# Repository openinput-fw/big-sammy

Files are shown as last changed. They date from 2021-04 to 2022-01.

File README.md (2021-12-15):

# big-sammy



[](https://github.com/openinput-fw)

Open source wired mouse hardware.

Please see the [documentation](https://big-sammy.readthedocs.io/en/latest) for more information.

## Specifications
- 8 kHz sampling rate support
- Zero latency switch debounce
- Onboard configuration memory
- 2 main mouse buttons (satellite* configuration for both)
- 2 side buttons (symmetric to allow easy left/right handedness)
- encoder + wheel button (satellite* configuration)
- RGB Led

`*meaning, a separate board from the core with the controller and sensor`

## Firmware

*big-sammy* is meant to run on [openinput](https://github.com/openinput-fw/openinput).

## License

This hardware is licensed under the [CERN-OHL-P v2](LICENSE) license.

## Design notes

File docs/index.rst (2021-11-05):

:hide-toc:

*********
big-sammy
*********
*big-sammy* is an open source wired mouse hardware implementation.

State of the project
====================

First prototype under testing, firmware support for openinput_ under development.

.. admonition:: Roadmap

   - Initial design |:+1:|
   - First prototype manufactured and assembled |:+1:|
   - Barebones firmware support |:+1:|
   - Documentation |:hammer:|
   - Hardware improvements |:hammer:|
   - First release

   ========== ================
   |:+1:|     Done!
   |:hammer:| Work in progress
   ========== ================

Specifications
==============

* 8 kHz sampling rate support
* Zero latency switch debounce
* Onboard configuration memory
* 2 main mouse buttons (satellite* configuration for both)
* 2 side buttons (symmetric to allow easy left/right handedness)
* encoder + wheel button (satellite* configuration)
* RGB Led

Hardware
========

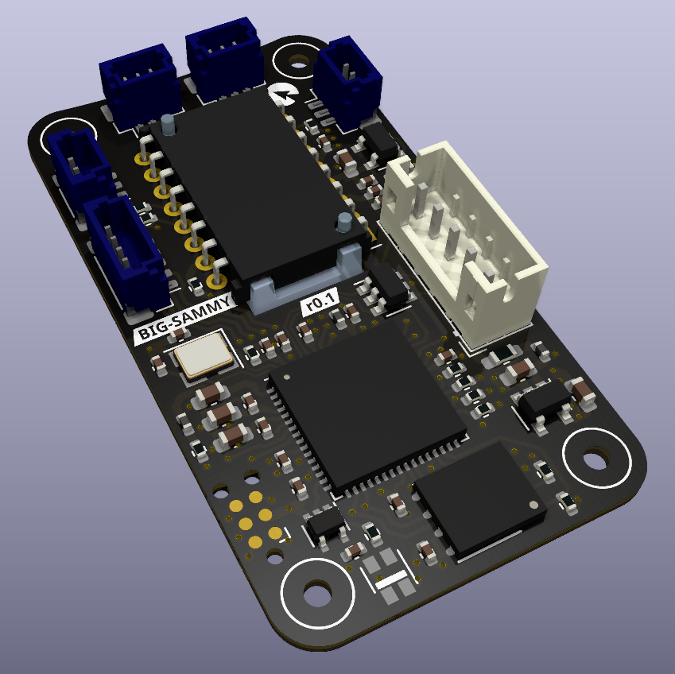
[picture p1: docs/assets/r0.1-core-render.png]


* ATSAMS70 MCU (ATSAMS70JxxB-M)
* Optical sensor [PMW3330, PMW3360, PMW3389, Truemove3]
* onboard conectors:
   * JST PH (2mm pitch) for USB
   * JST SH (1mm pitch) for stellite boards
* M2 mounting hardware

+--------------+
| USB   pinout |
+-----+--------+
| pin | func   |
+=====+========+
| 1 	| VCC    |
+-----+--------+
| 2 	| DM     |
+-----+--------+
| 3 	| DP     |
+-----+--------+
| 4 	| GND    |
+-----+--------+
| 5 	| Shield |
+-----+--------+

Peripheral boards are used for the buttons and encoder, available at generic-mouse-boards.

.. toctree::
   :caption: Development
   :hidden:

   Contributing <contributing/index>

.. toctree::
   :caption: External Links
   :hidden:

   Source <https://github.com/openinput-fw/big-sammy>
   Firmware <https://openinput.readthedocs.io>
   Issue Tracker <https://github.com/openinput-fw/big-sammy/issues>

.. _openinput: https://openinput.readthedocs.io

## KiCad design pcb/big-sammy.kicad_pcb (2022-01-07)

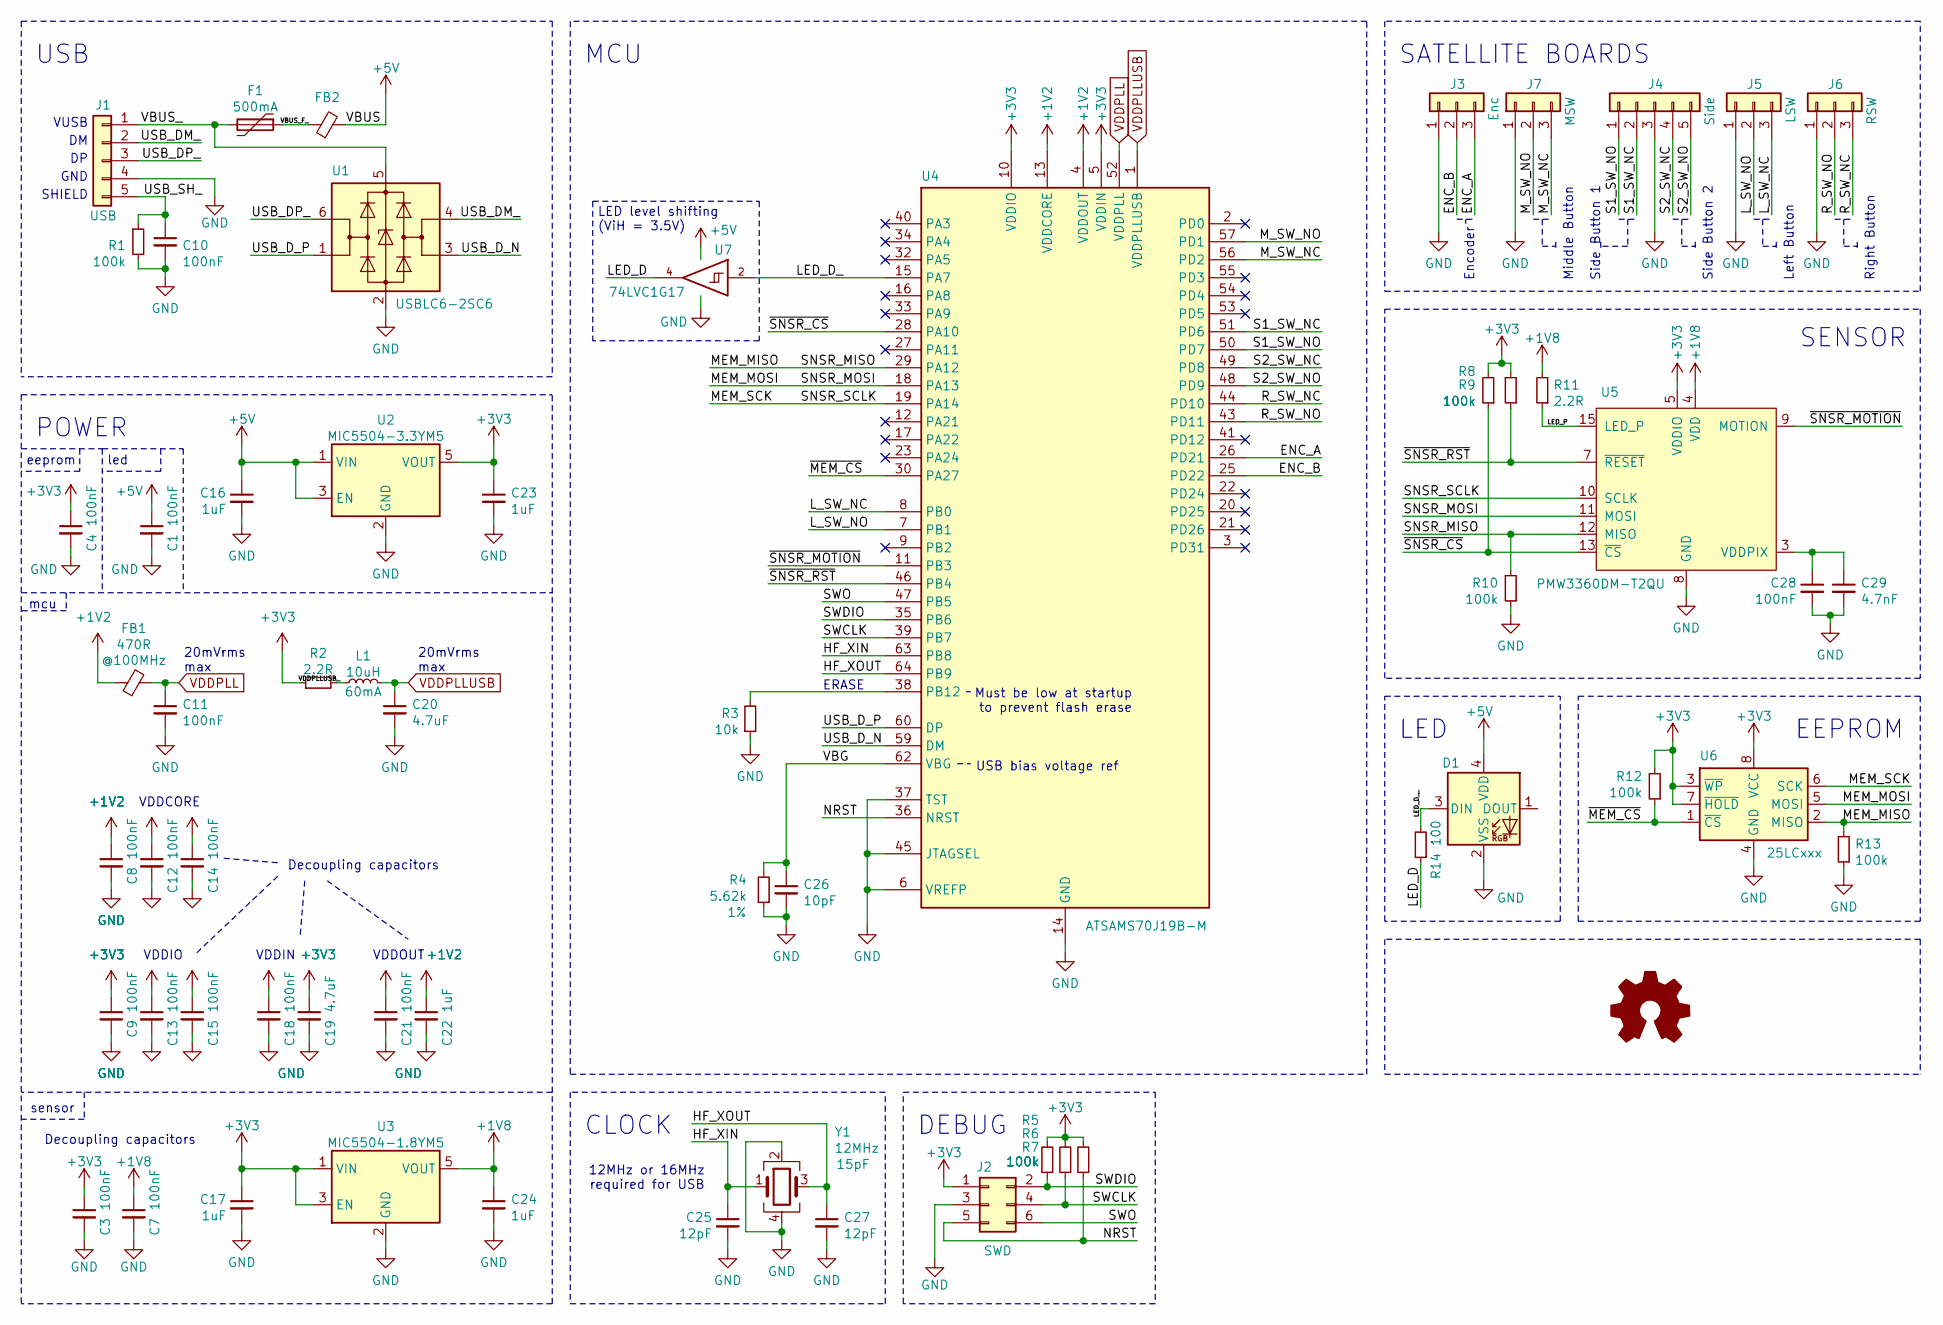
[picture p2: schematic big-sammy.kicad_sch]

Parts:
C1, C3, C4, C7, C8, C9, C10, C11, C12, C13, C14, C15, C18, C21, C28: 100nF; C_0402_1005Metric
C16, C17, C22, C23, C24: 1uF; C_0603_1608Metric
C19, C20: 4.7uF; C_0603_1608Metric
C25, C27: 12pF; C_0402_1005Metric
C26: 10pF; C_0402_1005Metric
C29: 4.7nF; C_0402_1005Metric
D1: ws2812-2020
F1: 500mA; Fuse_0603_1608Metric_Castellated
FB1: 470R; L_0402_1005Metric
FB2: L_0402_1005Metric
J1: USB; JST_PH_B5B-PH-K_1x05_P2.00mm_Vertical
J2: SWD; Tag-Connect_TC2030-IDC-NL_2x03_P1.27mm_Vertical
J3: Enc; JST_SH_BM03B-SRSS-TB_1x03-1MP_P1.00mm_Vertical
J4: Side; JST_SH_BM05B-SRSS-TB_1x05-1MP_P1.00mm_Vertical
J5: LSW; JST_SH_BM03B-SRSS-TB_1x03-1MP_P1.00mm_Vertical
J6: RSW; JST_SH_BM03B-SRSS-TB_1x03-1MP_P1.00mm_Vertical
J7: MSW; JST_SH_BM03B-SRSS-TB_1x03-1MP_P1.00mm_Vertical
L1: 10uH; L_0402_1005Metric
R1, R5, R6, R7, R8, R9, R10, R12, R13: 100k; R_0402_1005Metric
R2, R11: 2.2R; R_0402_1005Metric
R3: 10k; R_0402_1005Metric
R4: 5.62k; R_0402_1005Metric; Tolerance 1%
R14: 100; R_0402_1005Metric
U1: USBLC6-2SC6; SOT-23-6
U2: MIC5504-3.3YM5; SOT-23-5
U3: MIC5504-1.8YM5; SOT-23-5
U4: ATSAMS70J19B-M; QFN-64-1EP_9x9mm_P0.5mm_EP7.65x7.65mm
U5: PMW3360DM-T2QU; PMW3360
U6: 25LCxxx; DFN-S-8-1EP_6x5mm_P1.27mm
U7: 74LVC1G17; SOT-353_SC-70-5
Y1: 12MHz; Crystal_SMD_3225-4Pin_3.2x2.5mm

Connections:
+1V2: C8.1, C12.1, C14.1, C21.1, C22.1, FB1.1, U4.4 (VDDOUT), U4.13 (VDDCORE), U4.24 (VDDCORE), U4.61 (VDDCORE)
+1V8: C7.1, C24.1, R11.2, U3.5 (VOUT), U5.4 (VDD)
+3V3: C3.1, C4.1, C9.1, C13.1, C15.1, C17.1, C18.1, C19.1, C23.1, J2.1, R2.1, R5.2, R6.2, R7.2, R8.2, R9.2, R12.2, U2.5 (VOUT), U3.1 (VIN), U3.3 (EN), U4.5 (VDDIN), U4.10 (VDDIO), U4.42 (VDDIO), U4.58 (VDDIO), U5.5 (VDDIO), U6.3 (~WP), U6.7 (~HOLD), U6.8 (VCC)
+5V: C1.1, C16.1, D1.4 (VDD), FB2.2, U2.1 (VIN), U2.3 (EN), U7.5 (VCC)
/ENC_A: J3.3, U4.26 (PD21)
/ENC_B: J3.2, U4.25 (PD22)
/HF_XIN: C25.1, U4.63 (PB8), Y1.1
/HF_XOUT: C27.1, U4.64 (PB9), Y1.3
/LED_D: R14.1, U7.4
/LED_D_: U4.15 (PA7), U7.2
/LED_D__: D1.3 (DIN), R14.2
/LED_P: R11.1, U5.15 (LED_P)
/L_SW_NC: J5.3, U4.8 (PB0)
/L_SW_NO: J5.2, U4.7 (PB1)
/MEM_MISO: R10.2, R13.2, U4.29 (PA12), U5.12 (MISO), U6.2 (MISO)
/MEM_MOSI: U4.18 (PA13), U5.11 (MOSI), U6.5 (MOSI)
/MEM_SCK: U4.19 (PA14), U5.10 (SCLK), U6.6 (SCK)
/M_SW_NC: J7.3, U4.56 (PD2)
/M_SW_NO: J7.2, U4.57 (PD1)
/NRST: J2.5, R7.1, U4.36 (NRST)
/R_SW_NC: J6.3, U4.44 (PD10)
/R_SW_NO: J6.2, U4.43 (PD11)
/S1_SW_NC: J4.2, U4.51 (PD6)
/S1_SW_NO: J4.1, U4.50 (PD7)
/S2_SW_NC: J4.4, U4.49 (PD8)
/S2_SW_NO: J4.5, U4.48 (PD9)
/SWCLK: J2.4, R6.1, U4.39 (PB7)
/SWDIO: J2.2, R5.1, U4.35 (PB6)
/SWO: J2.6, U4.47 (PB5)
/USB_DM_: J1.2, U1.4 (I/O2)
/USB_DP_: J1.3, U1.6 (I/O1)
/USB_D_N: U1.3 (I/O2), U4.59 (DM)
/USB_D_P: U1.1 (I/O1), U4.60 (DP)
/USB_SH_: C10.1, J1.5, R1.1
/VBG: C26.1, R4.2, U4.62 (VBG)
/VBUS_: F1.2, J1.1, U1.5 (VBUS)
/VBUS_F_: F1.1, FB2.1
/VDDPLLUSB_: L1.1, R2.2
/~MEM_CS: R12.1, U4.30 (PA27), U6.1 (~CS)
/~SNSR_CS: R8.1, U4.28 (PA10), U5.13 (~CS)
/~SNSR_MOTION: U4.11 (PB3), U5.9 (MOTION)
/~SNSR_RST: R9.1, U4.46 (PB4), U5.7 (~RESET)
GND: C1.2, C3.2, C4.2, C7.2, C8.2, C9.2, C10.2, C11.2, C12.2, C13.2, C14.2, C15.2, C16.2, C17.2, C18.2, C19.2, C20.2, C21.2, C22.2, C23.2, C24.2, C25.2, C26.2, C27.2, C28.2, C29.2, D1.2 (VSS), J1.4, J2.3, J3.1, J4.3, J5.1, J6.1, J7.1, R1.2, R3.1, R4.1, R10.1, R13.1, U1.2 (GND), U2.2 (GND), U3.2 (GND), U4.6 (VREFP), U4.14 (GND), U4.31 (GND), U4.37 (TST), U4.45 (JTAGSEL), U4.65 (GND), U5.8 (GND), U6.4 (GND), U7.3 (GND), Y1.2, Y1.4
unnamed: C28.1, C29.1, U5.3 (VDDPIX)
unnamed: R3.2, U4.38 (PB12)
VDDPLL: C11.1, FB1.2, U4.52 (VDDPLL)
VDDPLLUSB: C20.1, L1.2, U4.1 (VDDPLLUSB)

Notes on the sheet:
Side Button 2
Left Button
DEBUG
USB
20mVrms max
CLOCK
SENSOR
USB bias voltage ref
VDDCORE
SHIELD
Right Button
VUSB
led
MCU
12MHz or 16MHz required for USB
mcu
Decoupling capacitors
Side Button 1
GND
POWER
sensor
Encoder
Middle Button
eeprom
SATELLITE BOARDS
VDDIO
LED
ERASE
LED level shifting (ViH = 3.5V)
VDDIN
Must be low at startup to prevent flash erase
EEPROM
VDDOUT

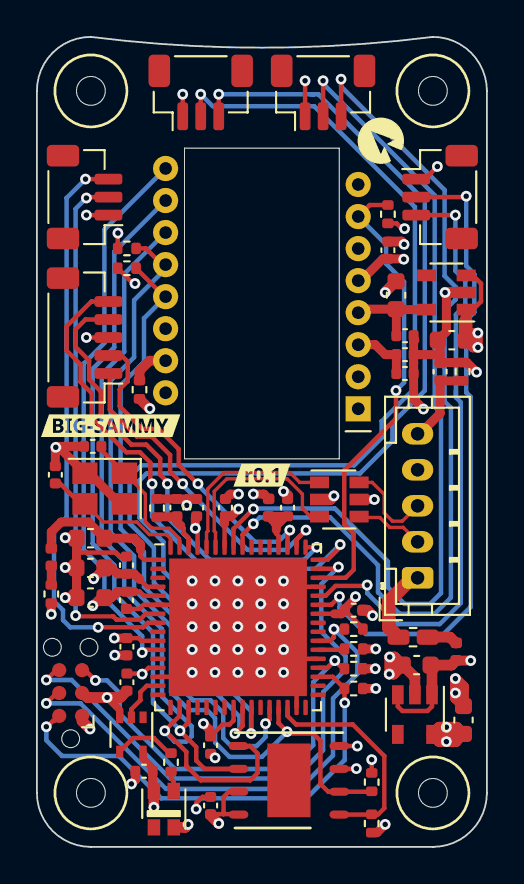
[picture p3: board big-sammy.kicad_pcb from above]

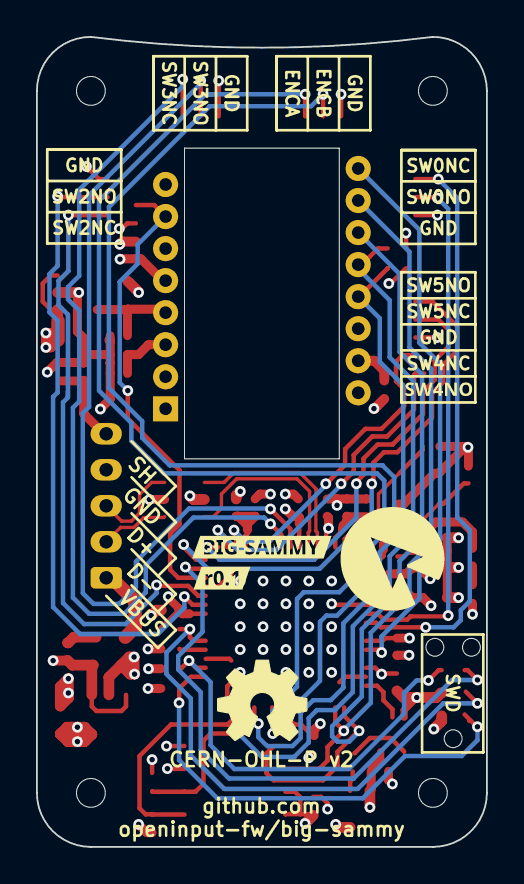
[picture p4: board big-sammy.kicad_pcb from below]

Board: 4 copper layers, 25.0 x 45.0 mm, 65 parts (3 on the bottom side), 47 nets.

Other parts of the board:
svg2mod, svg2mod#2, svg2mod#3, svg2mod#4, svg2mod#5: G***; svg2mod

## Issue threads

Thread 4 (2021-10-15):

Automated PCB and pinout renders for documentation

perigoso, 2021-10-15:
There are a couple projects out there that make pretty renders of pcb related stuff, it's something I'd like to play around with.

This issue serves as a reminder. (help is welcome ofcourse)

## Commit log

2021-04-10 hardware: add base projects
    [core.kicad_pcb, core.kicad_sch, encoder.kicad_pcb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]
2021-04-13 kicad: add local libraries
2021-04-13 schematic: implement core board
    [core.kicad_sch]
2021-04-13 schematic: add current repo url
    [encoder.kicad_sch, side.kicad_sch, switch.kicad_sch]
2021-04-13 git: kicad: add kicad lib backups to gitignore
2021-04-13 schematic: implement side boards
    [encoder.kicad_sch, side.kicad_sch, switch.kicad_sch]
2021-04-13 schematic: add missing library table
2021-04-13 schematic: core: add rgb led
    [core.kicad_sch]
2021-04-13 schematic: core: add labels
    [core.kicad_sch]
2021-04-13 readme: add RGB Led to spec list
2021-04-13 schematic: core: fix erase pull down value (internall 100k in parallel)
    [core.kicad_sch]
2021-04-13 name: renamed project
    [core.kicad_pcb, core.kicad_sch, encoder.kicad_pcb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]
2021-04-13 readme: mention more compatible sensors
2021-04-13 hardware: add project footprint table
2021-04-13 hardware: fix kicad table links
2021-04-13 schematic: core: changed encoder board pinout
    [core.kicad_sch]
2021-04-13 pcb: encoder: layout
    [encoder.kicad_pcb, encoder.kicad_sch]
2021-04-13 pcb: side: layout
    [side.kicad_pcb, side.kicad_sch]
2021-04-13 pcb: switch: layout
    [switch.kicad_pcb, switch.kicad_sch]
2021-04-20 pcb: core: component positioning
    [core.kicad_pcb, core.kicad_sch]
2021-04-21 kicad: libraries
2021-04-21 core: layout
    [core.kicad_pcb, core.kicad_sch]
2021-04-22 kicad: add M1.4 mounting hole
2021-04-22 core: finalize layout
    [core.kicad_pcb]
2021-04-22 switch: add alternative mounting points
    [switch.kicad_pcb]
2021-04-22 side: change mounting hardware from m2 to m1.4
    [side.kicad_pcb]
2021-04-22 encoder: rework encoder board
    [encoder.kicad_pcb, encoder.kicad_sch]
2021-04-22 rev: bum rev to r0.1
    [core.kicad_pcb, core.kicad_sch, encoder.kicad_pcb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]
2021-04-22 repo: update name and references to source
    [core.kicad_pcb, core.kicad_sch, encoder.kicad_pcb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]
2021-04-22 core: pcb: fixup encoder trace
    [core.kicad_pcb]
2021-04-22 core: pcb: fixup SW trace
    [core.kicad_pcb]
2021-04-30 pcb: move kicad project, seperate generic boards from repo
    [big-sammy.kicad_pcb, big-sammy.kicad_sch, encoder.kicad_pcb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]
2021-04-30 kicad: removed unused libs
2021-06-08 fix #1: typo in link to source
    [big-sammy.kicad_pcb]
2021-07-02 readme: add peripheral board reference
2021-10-29 docs: doc landing page formating and improvement
2022-01-07 kicad: save pcb with v6.0
    [big-sammy.kicad_pcb, big-sammy.kicad_sch]

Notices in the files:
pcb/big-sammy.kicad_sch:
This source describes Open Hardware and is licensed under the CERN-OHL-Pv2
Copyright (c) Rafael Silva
